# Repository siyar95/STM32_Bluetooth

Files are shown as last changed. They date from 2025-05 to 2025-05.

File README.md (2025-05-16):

# STM32_Bluetooth

A compact STM32WB55CEU6-based Bluetooth module designed for embedded wireless applications. This board features a u.FL antenna connector, USB-C interface, and UART communication — making it ideal for low-power wireless development and integration.

---

## 🔧 Features

- **Microcontroller**: STM32WB55CEU6 (Bluetooth 5.2 + Cortex-M4 + Cortex-M0+)
- **Bluetooth Antenna**: u.FL connector for external antenna
- **USB Interface**: USB-C for power and data
- **Communication**: UART breakout for serial interfacing
- **Power Supply**: 5V USBC --> 3.3V LDO regulator --> 1.2V SMPS (in the MCU) for efficient power conversion
- **Oscillators**:
  - 32 MHz HSE (for Bluetooth stack)
  - 32.768 kHz LSE (for RTC and low-power modes)

---

## 🧱 PCB Stackup (4-layer)

| Layer | Purpose |
|---|---|
| L1 | Signal (Top) |
| L2 | Ground Plane |
| L3 | Ground Plane |
| L4 | Power / Signal |

Optimized for signal integrity, RF performance, and low EMI.

---

## 🧩 Ideal For

- Bluetooth Low Energy (BLE) applications
- Custom wearable or IoT devices
- Prototyping wireless peripherals with STM32Cube ecosystem
- Projects needing UART or USB-C connectivity alongside BLE

---

## 📡 Notes

- Make sure to connect a suitable external antenna via the u.FL connector.
- Crystal oscillator frequencies comply with STM32WB Bluetooth stack requirements.
- USB-C supports both power and USB device functionality.

---

## 🛠️ Tools

- Designed in **KiCad**
- Program using **STM32CubeIDE** or **STM32CubeProgrammer**

## Screenshots






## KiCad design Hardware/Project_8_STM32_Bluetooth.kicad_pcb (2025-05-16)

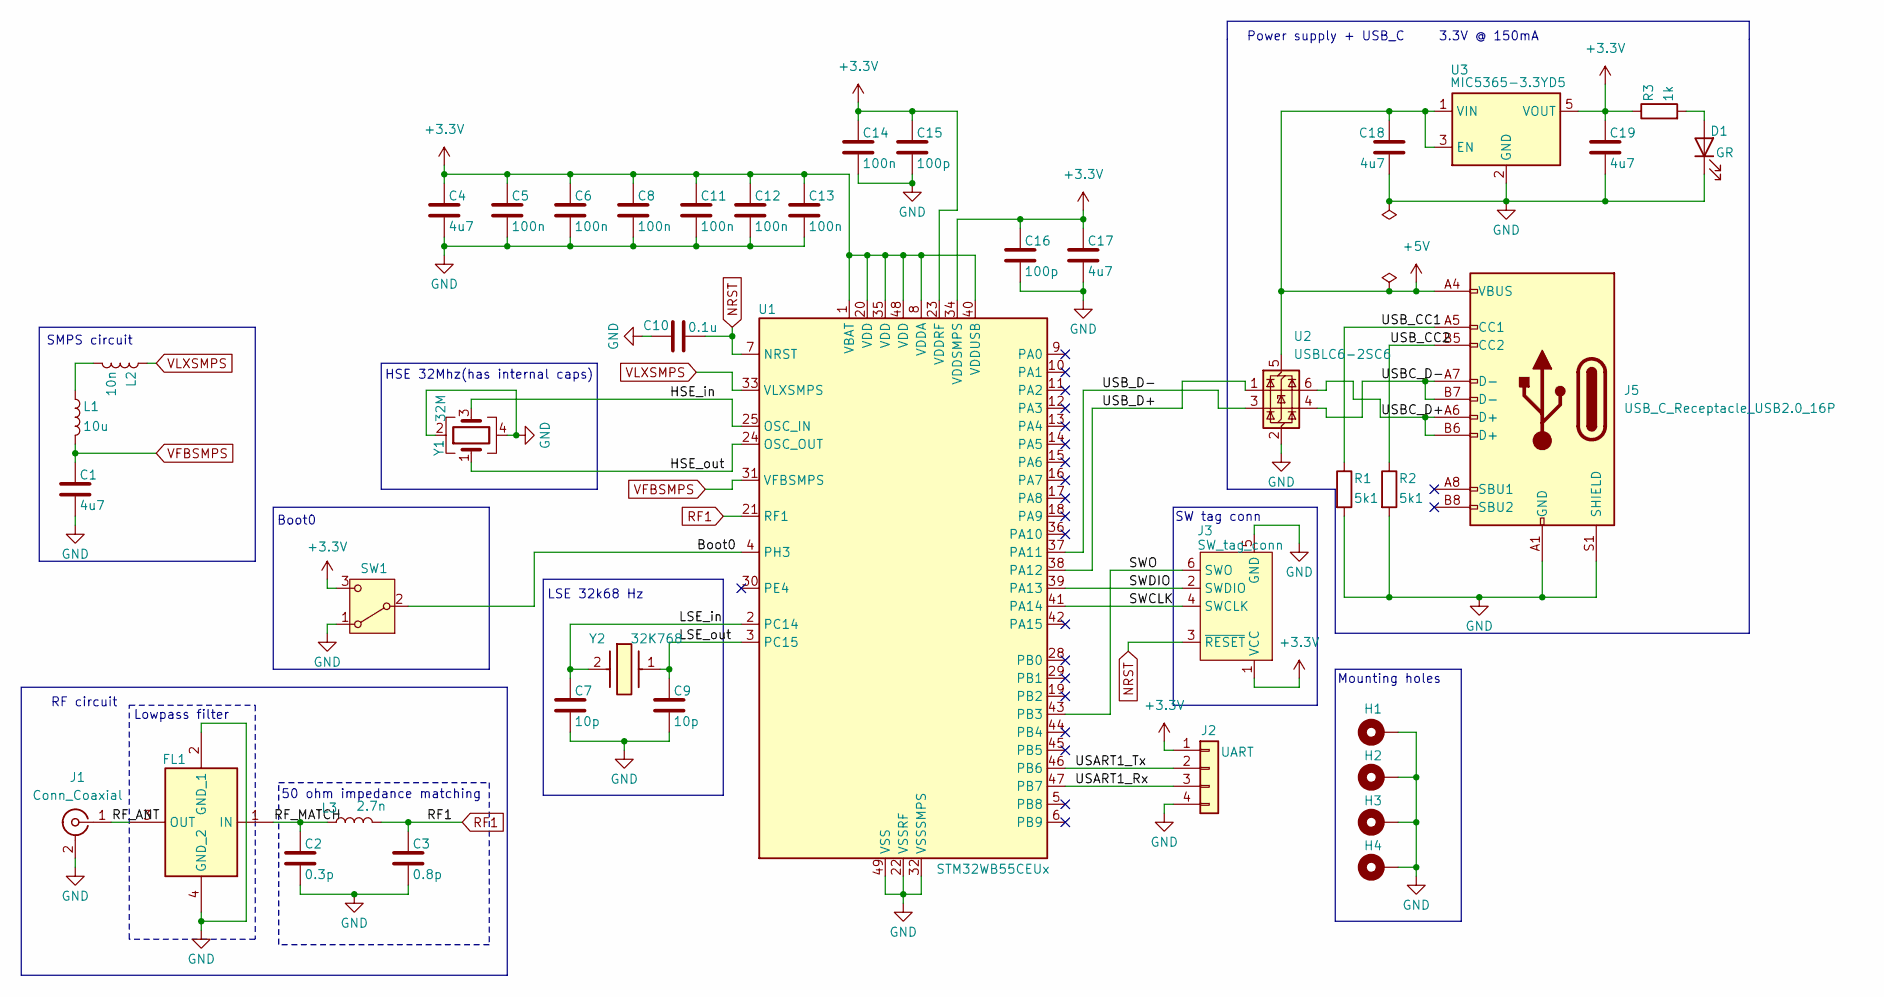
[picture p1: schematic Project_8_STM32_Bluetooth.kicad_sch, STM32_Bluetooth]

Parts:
C1, C4, C17: 4u7; C_0402_1005Metric
C2: 0.3p; C_0402_1005Metric
C3: 0.8p; C_0402_1005Metric
C5, C6, C8, C11, C12, C13, C14: 100n; C_0402_1005Metric
C7, C9: 10p; C_0402_1005Metric
C10: 0.1u; C_0402_1005Metric
C15, C16: 100p; C_0402_1005Metric
C18, C19: 4u7; C_0805_2012Metric
D1: GR; LED_0805_2012Metric
FL1: DLF162500LT-5028A1; LPF; Mouser Part Number 810-DLF16250LT5028A1
H1, H2, H3, H4: MountingHole_Pad; MountingHole_2.5mm_Pad_Via
J1: Conn_Coaxial; U.FL_Hirose_U.FL-R-SMT-1_Vertical
J2: UART; PinHeader_1x04_P2.54mm_Vertical
J3: SW_tag_conn; Tag-Connect_TC2030-IDC-FP_2x03_P1.27mm_Vertical
J5: USB_C_Receptacle_USB2.0_16P; USB_C_Receptacle_XKB_U262-16XN-4BVC11
L1: 10u; L_0805_2012Metric
L2: 10n; L_0402_1005Metric
L3: 2.7n; L_0402_1005Metric
R1, R2: 5k1; R_0402_1005Metric
R3: 1k; R_0402_1005Metric
SW1: SW_SPDT; SW_SPDT_PCM12
U1: STM32WB55CEUx; QFN-48-1EP_7x7mm_P0.5mm_EP5.6x5.6mm
U2: USBLC6-2SC6; SOT-23-6
U3: MIC5365-3.3YD5; SOT-23-5
Y1: 32M; Crystal_SMD_2016-4Pin_2.0x1.6mm
Y2: 32K768; NX2012SA32768KSTDMUB1; Mouser Part Number 344-NX2012SA32768K1

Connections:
+3.3V: C4.1, C5.1, C6.1, C8.1, C11.1, C12.1, C13.1, C14.1, C15.1, C16.1, C17.1, C19.1, J2.1, J3.1 (VCC), R3.1, SW1.3 (C), U1.1 (VBAT), U1.8 (VDDA), U1.20 (VDD), U1.23 (VDDRF), U1.34 (VDDSMPS), U1.35 (VDD), U1.40 (VDDUSB), U1.48 (VDD), U3.5 (VOUT)
+5V: C18.1, J5.A4 (VBUS), J5.A9 (VBUS), J5.B4 (VBUS), J5.B9 (VBUS), U2.5 (VBUS), U3.1 (VIN), U3.3 (EN)
/Boot0: SW1.2 (B), U1.4 (PH3)
/HSE_in: U1.25 (OSC_IN), Y1.3
/HSE_out: U1.24 (OSC_OUT), Y1.1
/LSE_in: C7.1, U1.2 (PC14), Y2.2 (CRYSTAL)
/LSE_out: C9.1, U1.3 (PC15), Y2.1 (CRYSTAL)
/RF_ANT: FL1.3 (OUT), J1.1 (In)
/RF_MATCH: C2.1, FL1.1 (IN), L3.1
/SWCLK: J3.4 (SWCLK), U1.41 (PA14)
/SWDIO: J3.2 (SWDIO), U1.39 (PA13)
/SWO: J3.6 (SWO), U1.43 (PB3)
/USART1_Rx: J2.3, U1.47 (PB7)
/USART1_Tx: J2.2, U1.46 (PB6)
/USBC_D+: J5.A6 (D+), J5.B6 (D+), U2.6 (I/O1)
/USBC_D-: J5.A7 (D-), J5.B7 (D-), U2.4 (I/O2)
/USB_CC1: J5.A5 (CC1), R1.1
/USB_CC2: J5.B5 (CC2), R2.1
/USB_D+: U1.38 (PA12), U2.1 (I/O1)
/USB_D-: U1.37 (PA11), U2.3 (I/O2)
GND: C1.2, C2.2, C3.2, C4.2, C5.2, C6.2, C7.2, C8.2, C9.2, C10.2, C11.2, C12.2, C13.2, C14.2, C15.2, C16.2, C17.2, C18.2, C19.2, D1.1 (K), FL1.2 (GND_1), FL1.4 (GND_2), H1.1, H2.1, H3.1, H4.1, J1.2 (Ext), J2.4, J3.5 (GND), J5.A1 (GND), J5.A12 (GND), J5.B1 (GND), J5.B12 (GND), J5.S1 (SHIELD), R1.2, R2.2, SW1.1 (A), U1.22 (VSSRF), U1.32 (VSSSMPS), U1.49 (VSS), U2.2 (GND), U3.2 (GND), Y1.2, Y1.4
NRST: C10.1, J3.3 (~RESET), U1.7 (NRST)
unnamed: D1.2 (A), R3.2
unnamed: L1.1, L2.2
RF1: C3.1, L3.2, U1.21 (RF1)
VFBSMPS: C1.1, L1.2, U1.31 (VFBSMPS)
VLXSMPS: L2.1, U1.33 (VLXSMPS)

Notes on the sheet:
SW tag conn
Boot0
50 ohm impedance matching
Lowpass filter
LSE 32k68 Hz
SMPS circuit
Mounting holes
RF circuit
Power supply + USB_C 3.3V @ 150mA
HSE 32Mhz(has internal caps)

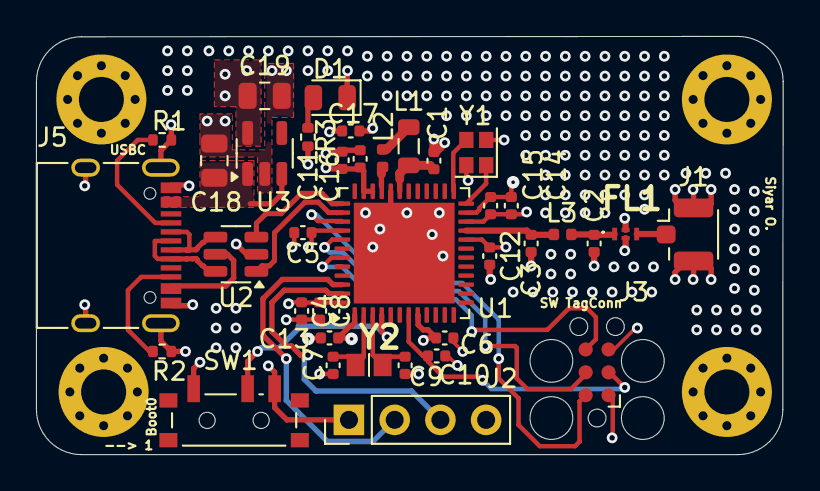
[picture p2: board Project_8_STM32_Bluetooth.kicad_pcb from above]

Board: 4 copper layers, 41.5 x 23.2 mm, 41 parts (0 on the bottom side), 27 nets.

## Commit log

2025-05-16 Update and rename Project_8_STM32_Bluetooth.kicad_pcb to Hardware/Project_8_STM32_Bluetooth.kicad_pcb
    [Project_8_STM32_Bluetooth.kicad_pcb]
2025-05-16 Update and rename Project_8_STM32_Bluetooth.kicad_sch to Hardware/Project_8_STM32_Bluetooth.kicad_sch
    [Project_8_STM32_Bluetooth.kicad_sch]
